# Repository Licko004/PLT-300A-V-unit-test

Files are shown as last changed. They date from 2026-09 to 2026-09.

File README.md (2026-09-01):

# V-unit test using PLT-300A

## Introduction
This repository describes the test procedure for testing the V-unit, it also includes necesarry operator instructions to preform said test.
The testing of the V-unit is done with the PLT-300A, through designated .yaml files, which include the necesarry test steps.
Before preforming the test the operator should follow [operator instructions](#Operator-instructions), to connect the V-unit and handle test fails.

If you wish to assemble/reprint/fix the setup, the 3D CAD models can be found in [3D models](https://github.com/Licko004/PLT-300A_V-unit-test/tree/main/3D-models).

To preform this test you need: 
1. PLT-300A **with an internet connection** this is easily achieved through the provided Ethernet port
2. The correct test plan on the PLT, consisting of the [Full test yaml file](https://github.com/Licko004/PLT-300A_V-unit-test/blob/main/Full_test_V0.0.7.yaml), the uploaded version should be the highest avaliable

## Test procedure/steps

1. Firstly the QR code, containg the serial number of the currently tested V-unit is scanned, using the provided optical scanner
2. Then the V-unit should be setup according to [setting up V-unit](#Setting-up-V-unit)
3. The PLT measures pressures measured by the internal/reference V-unit and the currently tested V-unit, it then compares both pressures, to indicate any malfunctioning of the pressure sensor
4. An MCU health check is preformed, the test setup includes an internal MCU in form of a Arduino Nano, which is responsible for PWM generation for pump control. More on the wirring and the whole setup can be seen on the [connections diagram](https://github.com/Licko004/PLT-300A_V-unit-test/blob/main/diagrams-connections/V-unit_connection_diagram%20(1).pdf)
5. In this step there is a **test to confirm, the V-unit can achieve vacuum**, this is done by driving the pump with different PWM duty cycles and measuring if the pressure has reached the desired pressure after a set amount of time. The PWM then increments and the check is done again. The duty cycle is incremented in steps: 50%, 75% and 100%. The MCU has custom firmware flashed, which can be found [here](https://github.com/Licko004/PLT-300A_V-unit-test/tree/main/MCU-firmware)
6. The next step is a **RELEASE TEST** which is a test to confirm the V-unit can quickly release pressure and in turn confirm that the valve is working
7. The final step is a **LEAKAGE TEST** which is done by driving the pump, which creates a vacuum, then the pump is turned off and the valve is left closed. Pressure is remeasured after a set amount of time. The measured pressure should be within the set boundaries, to confim, there are no major leaks. 

## Operator instructions

The operator instruction can be divided in to different tasks:
1. The operator **Scans the QR code** on the currently tested V-unit
2. The operator is given 30 seconds to **connect the V-unit, mechanically, electricaly and connect the vacuum vessel**. The setting up is described in [Setting up V-unit](#setting-up-v-unit).
3. Once **step 2 is done** the operator **confirms the setup, by pressng START/PASS button**
4. The operator should be focused on the test, check for any visible leaks, which might indicate leaks due to bad setup, or any unexpected noises.
5. After the **test is done** the operator should **press the PASS button, enough times to enter the main menu of the PLT** after that the operator can **disconnect the V-unit**.
5. For any FAIL debugging, the operator should refer to the [PLT cloud reports](https://dewesoftrealtimebodysense.pltcloud.com/) automatically published after each test.
### Setting up V-unit
The setting up of the V-unit is described here:
1. The operator connects one end of the air tube to the V-unit
2. The operator **places the V-unit into its holder** (look at image below for reference)
3. The operator **connects the cable harness to the V-unit** 
4. The operator **pushes the loose end of the air tube into the push-fit connector**.
All of the V-unit preparations steps can be better understood, by refering to the image below:
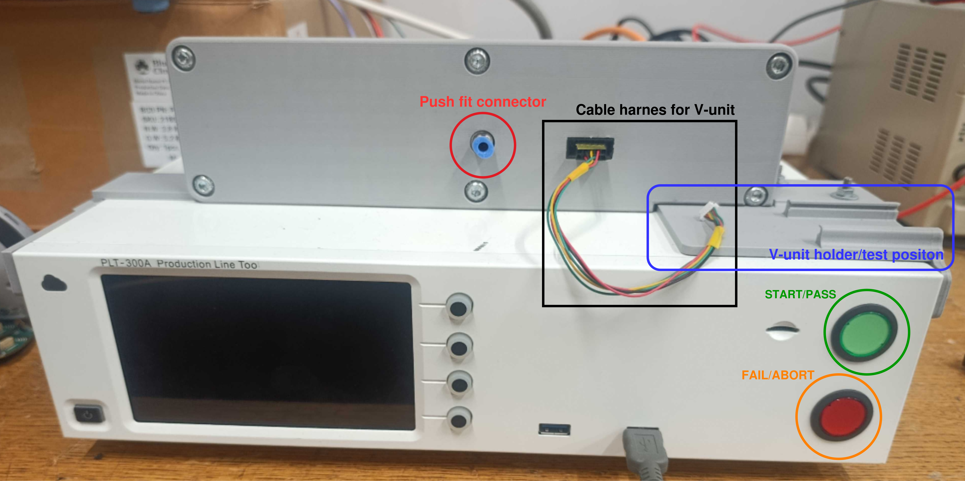
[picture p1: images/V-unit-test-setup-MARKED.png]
Test setup and placement of connections


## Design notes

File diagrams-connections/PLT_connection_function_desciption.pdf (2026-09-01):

Sheet1

PLT pins
Connector | Pin name | Pin nr. | Description
HD78 | DUT GND | 10 | Ground
HD78 | DATP07 | 26 | Reference pressure sensor value
HD78 | DATP08 | 28 | V-unit pressure sensor value
HD78 | DDTP09 | 49 | Valve control pin
HD78 | DDTP10 | 50 | PWM Duty increment signal
HD78 | DDTP11 | 51 | Pump stop/start control pin

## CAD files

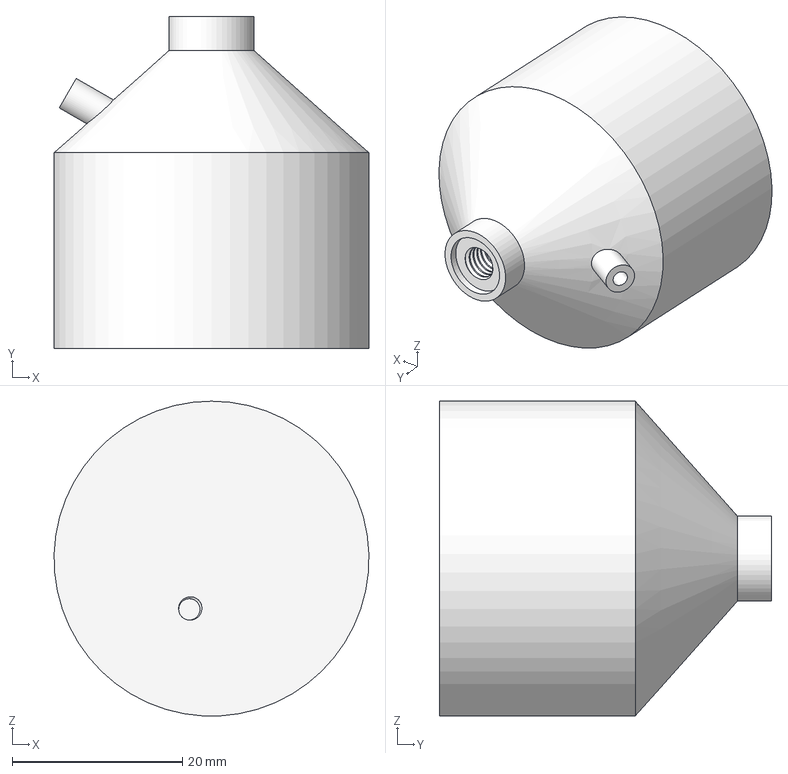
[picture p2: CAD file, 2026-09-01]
3D-models/vacuum-vessel.step
37.0 x 39.0 x 37.0 mm

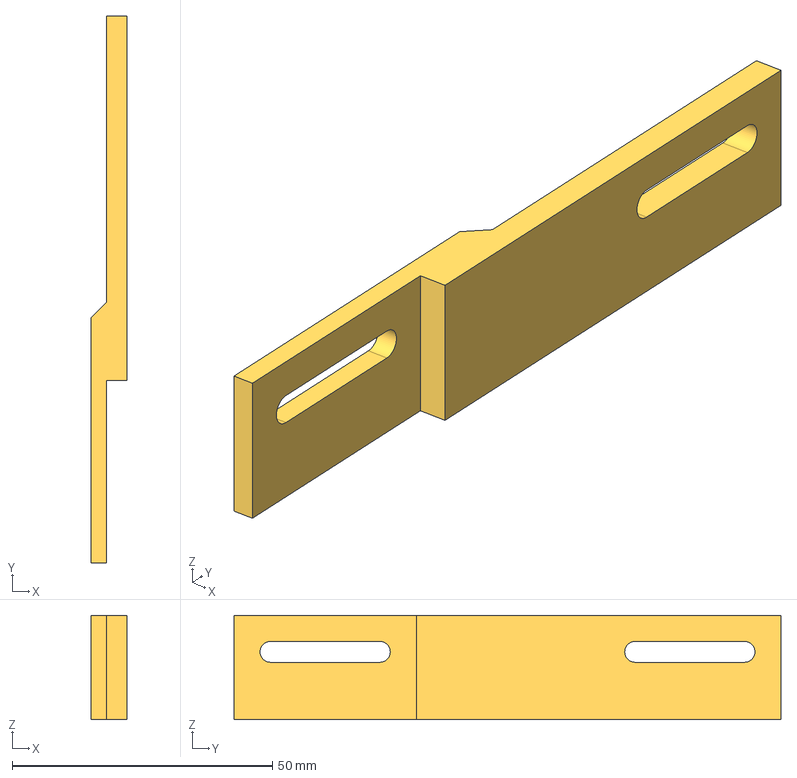
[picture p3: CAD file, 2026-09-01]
3D-models/left-side-extension.step
7.00 x 105.0 x 20.0 mm

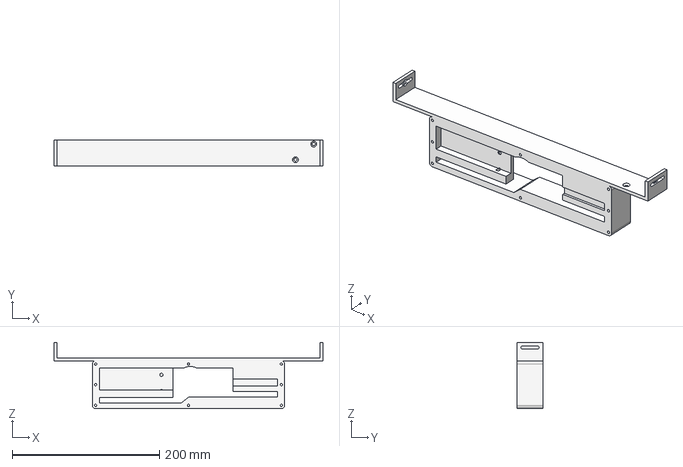
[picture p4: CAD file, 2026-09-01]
3D-models/frame.step
365.0 x 35.0 x 90.0 mm

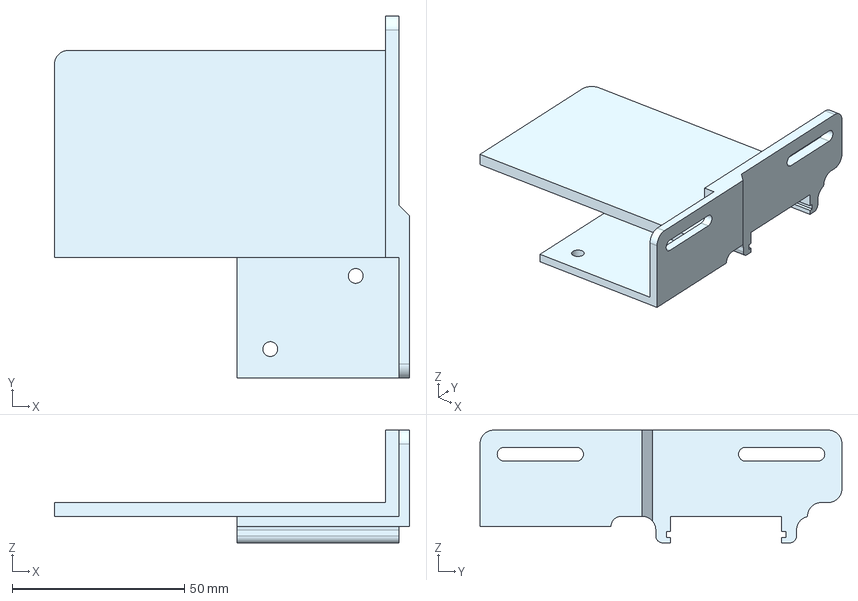
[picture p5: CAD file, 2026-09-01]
3D-models/frame-v-unit-holder.step
103.0 x 105.0 x 32.7 mm

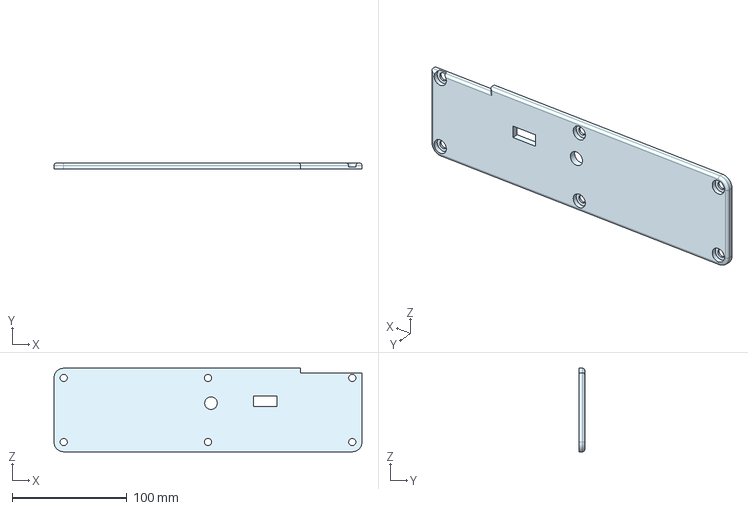
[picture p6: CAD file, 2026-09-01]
3D-models/cover.step
269.0 x 5.00 x 73.0 mm

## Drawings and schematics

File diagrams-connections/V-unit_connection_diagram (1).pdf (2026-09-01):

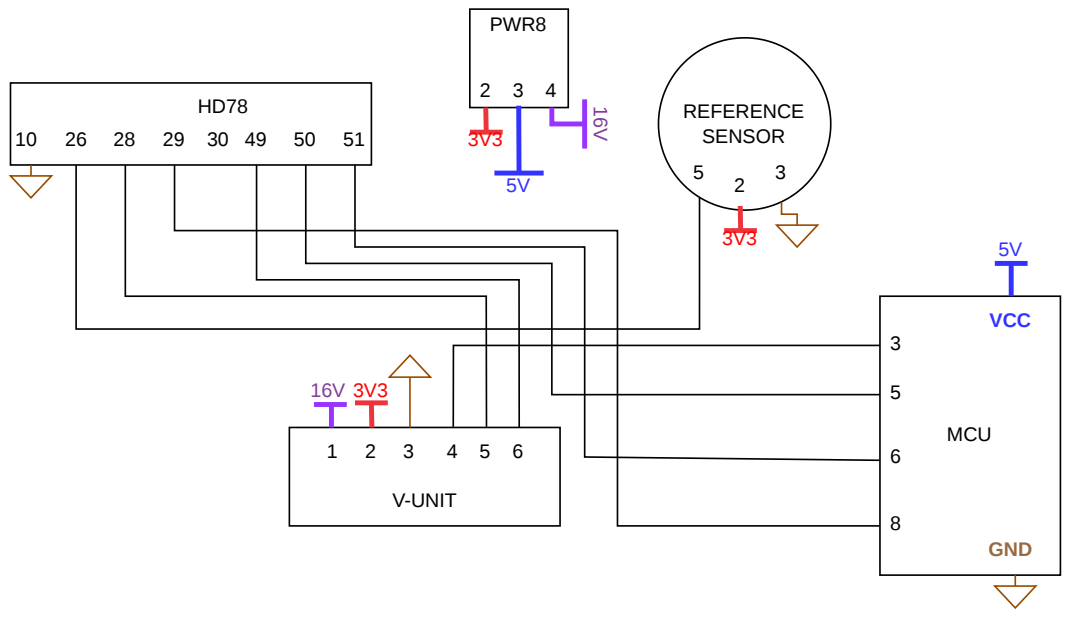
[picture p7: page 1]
MCU; VCC; GND; PWR8; REFERENCE SENSOR; V-UNIT

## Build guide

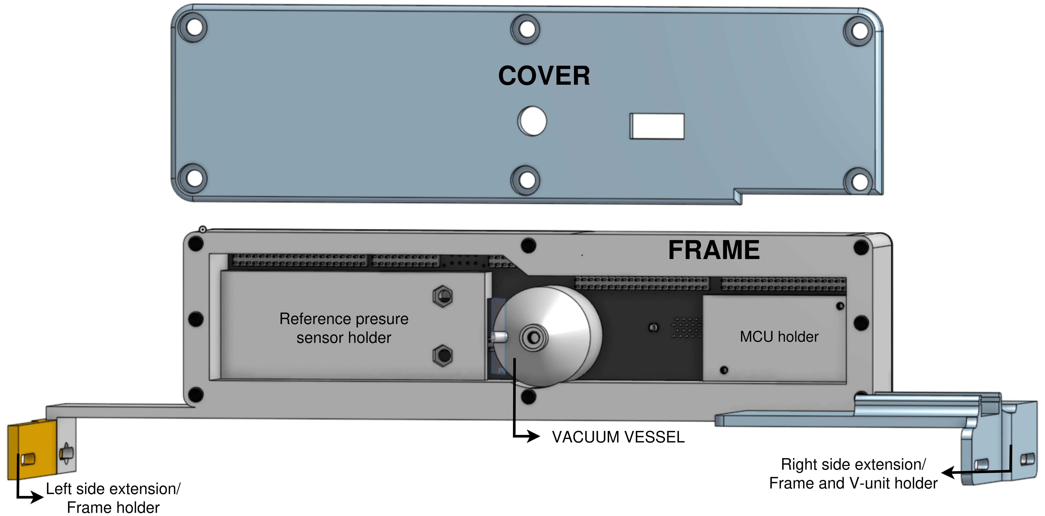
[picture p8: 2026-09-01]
images/Assembly-3D-model-MARKED.png

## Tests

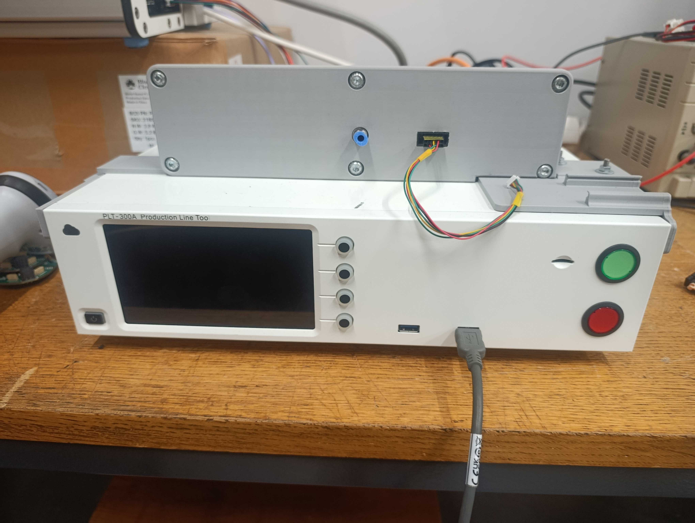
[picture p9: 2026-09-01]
images/V-unit-test-setup-image.png

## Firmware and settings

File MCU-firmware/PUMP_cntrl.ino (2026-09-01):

#include <Timer.h>

Timer timer;

int PWM_pin = 3;
int CNTRL = 5;
int state_cnt = 0;
int stop = 6;
int MCU_fault = 8;

unsigned long start_time = 0;
unsigned long elapsed_ms = 0;


void setup() {
  // put your setup code here, to run once:
pinMode(PWM_pin, OUTPUT);
pinMode(CNTRL, INPUT);
pinMode(stop, INPUT);
pinMode(MCU_fault, OUTPUT);
//Serial.begin(115200);

/***********MCU fault signal send*********************/
digitalWrite(MCU_fault, HIGH);

}

void loop() {
  // put your main code here, to run repeatedly:
/***********PWM control for PUMP*********************/
int CNTRL_state = digitalRead(CNTRL);
int stop_state = digitalRead(stop);

if (CNTRL_state == 1) {
  state_cnt ++;
  delay(50);
}
if (stop_state == 1){
  switch (state_cnt) {
    // case 1:
    //   analogWrite(PWM_pin, 64);
    //   break;
    case 1:
      analogWrite(PWM_pin, 127);
      break;
    // case 3:
    //   analogWrite(PWM_pin, 191);
    //   break;
    case 2: 
      analogWrite(PWM_pin, 255);
      break;
    case 3:
      analogWrite(PWM_pin, 191); //Set PWM to 75% for leakage test
      break;
    default:
      analogWrite(PWM_pin, 0);
      break;
}
}else {
  analogWrite(PWM_pin, 0);
}

}

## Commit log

2026-09-01 Added arduino FW for PWM control
2026-09-01 Added 3D models of assembly
    [QuickLink_210 - Pokrov V2.1.step, QuickLink_210-L_podalsek.step, QuickLink_210-Okvir_PLT.step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]
2026-09-01 Renamed 3D CAD files to match names in png description
    [cover.step, frame-v-unit-holder.step, frame.step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]
2026-09-01 Added fxed marked image of assembly
